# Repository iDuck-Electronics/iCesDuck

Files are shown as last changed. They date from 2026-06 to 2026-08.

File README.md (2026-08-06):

# iCesDuck

<p align="center">
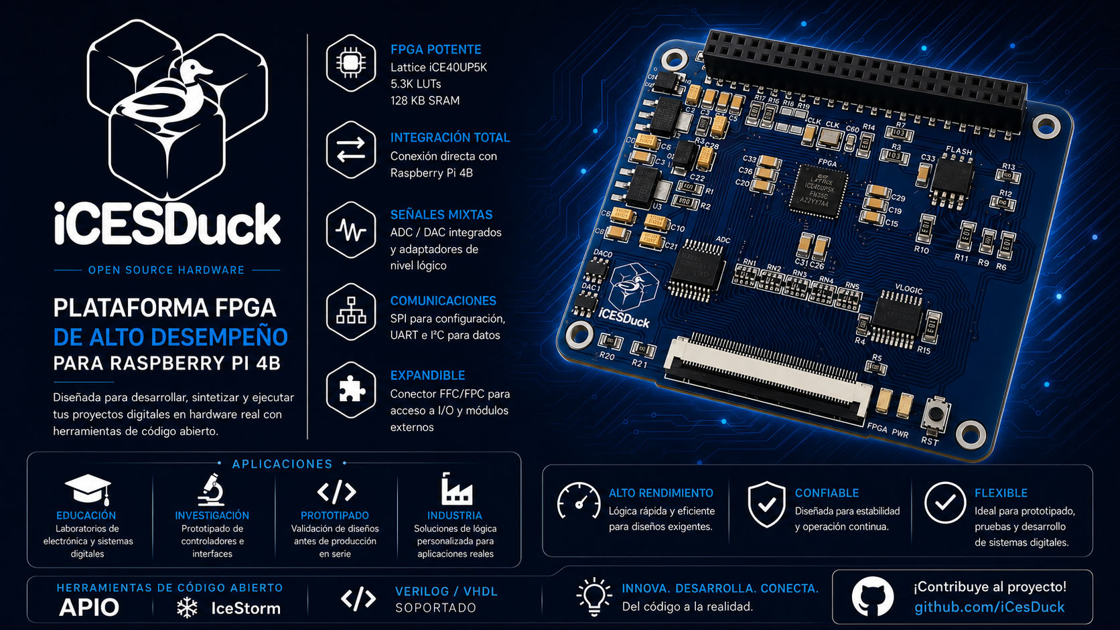
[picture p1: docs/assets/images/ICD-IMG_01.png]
iCesDuck — Plataforma FPGA para Raspberry Pi 4B
  
</p>

<p align="center">
  
  
  
  
</p>

<p align="center">
  <strong>Plataforma FPGA de código abierto para Raspberry Pi 4B</strong><br>
  Síntesis, programación y supervisión de lógica digital en una arquitectura compacta, modular y orientada a la experimentación.
</p>

---

## Descripción general

**iCesDuck** es una placa de desarrollo basada en la FPGA **Lattice iCE40UP5K**, diseñada para trasladar proyectos escritos en **Verilog** y **VHDL** desde la simulación HDL hasta su ejecución en hardware real.

La **Raspberry Pi 4B** funciona como sistema anfitrión y entorno principal de trabajo: realiza la síntesis, genera el bitstream, programa la FPGA y supervisa el comportamiento de la plataforma. Esta integración permite desarrollar, probar y depurar diseños digitales sin depender de herramientas propietarias o programadores externos especializados.

La placa incorpora recursos para trabajar con señales digitales y mixtas, entre ellos:

- FPGA programable **Lattice iCE40UP5K**.
- Convertidores **ADC** y **DAC**.
- Adaptadores de nivel lógico.
- Memoria de configuración.
- Reloj de **48 MHz**.
- Comunicación mediante **SPI**, **I²C** y **UART**.
- Conector **FFC/FPC** para expansión y acceso a señales externas.
- Conector GPIO espejo compatible con Raspberry Pi 4B.

<p align="center">
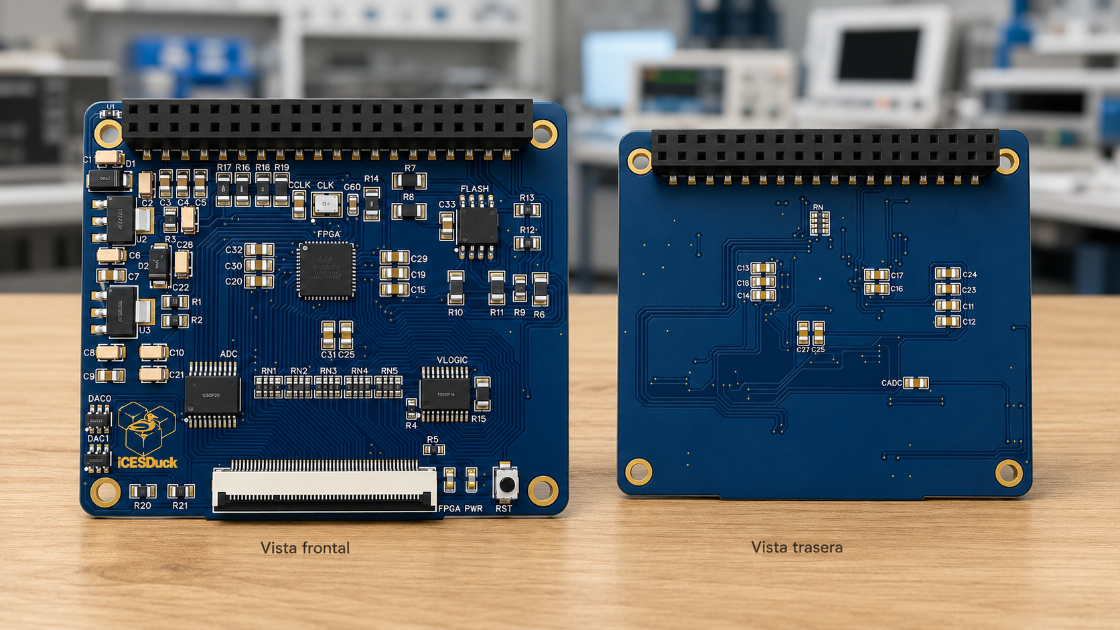
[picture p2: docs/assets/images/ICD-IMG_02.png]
Vista frontal y posterior de la placa iCesDuck
  
</p>

> **Objetivo del proyecto:** ofrecer una plataforma abierta y documentada para aprender, investigar y prototipar sistemas digitales con FPGA, utilizando la Raspberry Pi como unidad de desarrollo, programación y supervisión.

<p align="center">
  <a href="docs/README.md">
    
  </a>
  &nbsp;
  <a href="hardware/README.md">
    
  </a>
  &nbsp;
  <a href="software/README.md">
    
  </a>
</p>

<p align="center">
  <a href="examples/README.md">
    
  </a>
  &nbsp;
  <a href="tests/README.md">
    
  </a>
</p>

---

## Características principales

<table>
  <thead>
    <tr>
      <th width="20%" align="left">Característica</th>
      <th width="24%" align="left">Especificación</th>
      <th width="48%" align="center">Distribución de componentes</th>
    </tr>
  </thead>
  <tbody>
    <tr>
      <td><strong>FPGA</strong></td>
      <td>Lattice iCE40UP5K</td>
      <td rowspan="11" align="center" valign="middle">
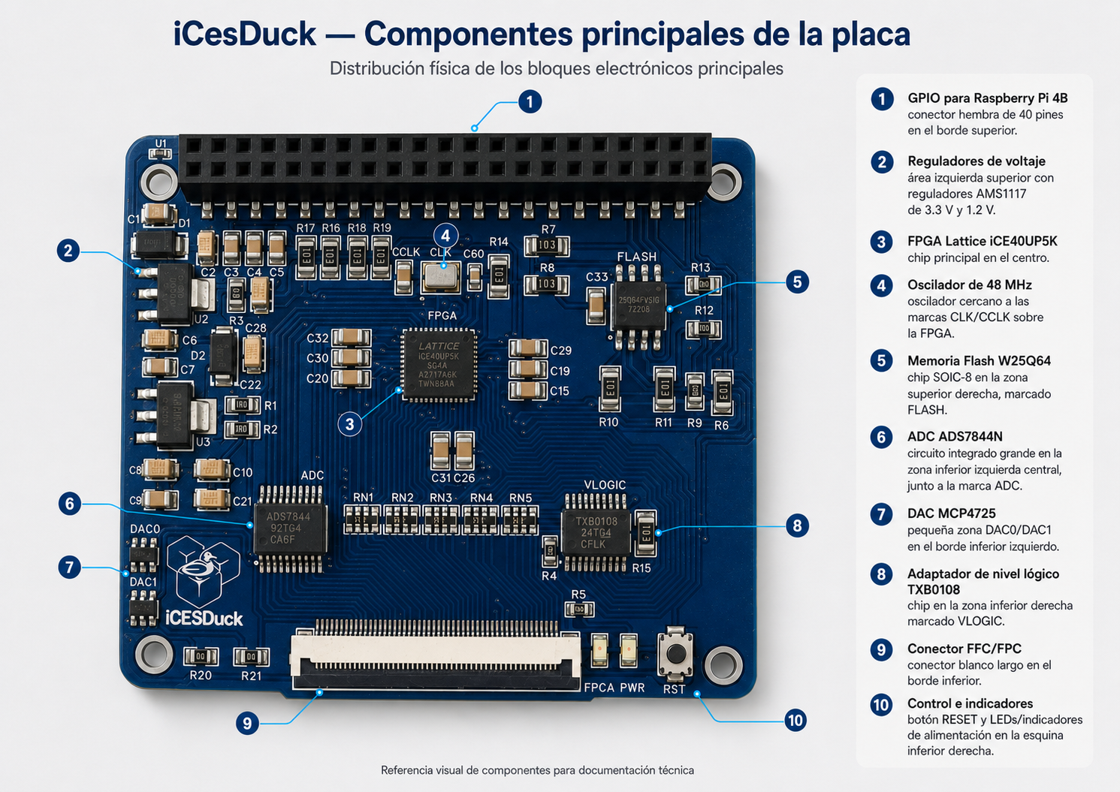
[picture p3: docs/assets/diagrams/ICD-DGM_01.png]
Distribución de los principales componentes de iCesDuck
        
        <br>
        <sub><em>Distribución general de los principales bloques electrónicos de la placa.</em></sub>
      </td>
    </tr>
    <tr><td><strong>Capacidad lógica</strong></td><td>5,280 LUTs</td></tr>
    <tr><td><strong>Memoria interna</strong></td><td>128 KB de SRAM</td></tr>
    <tr><td><strong>Compatibilidad</strong></td><td>Raspberry Pi 4B</td></tr>
    <tr><td><strong>Nivel lógico principal</strong></td><td>3.3 V</td></tr>
    <tr><td><strong>Interfaces</strong></td><td>SPI, I²C y UART</td></tr>
    <tr><td><strong>Conversión de señales</strong></td><td>ADC y DAC integrados</td></tr>
    <tr><td><strong>Reloj</strong></td><td>48 MHz</td></tr>
    <tr><td><strong>Lenguajes HDL</strong></td><td>Verilog y VHDL</td></tr>
    <tr><td><strong>Toolchain</strong></td><td>APIO, Yosys, nextpnr e IceStorm</td></tr>
    <tr><td><strong>Expansión</strong></td><td>GPIO espejo y conector FFC/FPC</td></tr>
  </tbody>
</table>

---

## Aplicaciones

- **Educación:** laboratorios de sistemas digitales, FPGA, arquitectura de computadores y electrónica embebida.
- **Investigación:** validación de controladores, interfaces digitales y lógica de propósito específico.
- **Prototipado:** pruebas funcionales antes de migrar un diseño a otra FPGA o a una solución dedicada.
- **Depuración HDL:** ejecución de testbench, comparación de resultados y validación en hardware real.
- **Señales mixtas:** adquisición, procesamiento y generación de señales mediante ADC, DAC y adaptadores de nivel.

---

## Revisiones de hardware

El desarrollo de iCesDuck se mantiene en evolución continua. Conforme se identifiquen errores, se validen nuevos bloques, se incorporen mejoras o se generen nuevas revisiones de hardware, los cambios correspondientes serán documentados y publicados en este repositorio para mantener la trazabilidad técnica del proyecto.

| Revisión | Estado | Ubicación |
|---|---|---|
| **V1.A1** | Primera revisión funcional con errores identificados | [`iCesDuck V1.A1`](hardware/boards-iCesDuck/v1-a1/) |
| **V1.A2** | Segunda revisión en desarrollo | [`iCesDuck V1.A1`](hardware/boards-iCesDuck/v1-a2/) |

---

## Explora iCesDuck

El repositorio está organizado por áreas especializadas. Cada una representa una etapa concreta del desarrollo, desde el diseño electrónico de la placa hasta la creación, programación y validación de proyectos HDL.

> **Ruta recomendada:** comienza con la documentación, ejecuta un ejemplo HDL y después entra al software, al hardware o a las pruebas según el área que quieras desarrollar.

<details>
<summary>
  <strong>🔷 Hardware iCesDuck</strong>
  <code>PCB</code>
  <code>EasyEDA</code>
  <code>fabricación</code>
</summary>

<br>

<div align="center">
  Diseño electrónico, revisiones y fabricación de iCesDuck
  <br>
  <sub><em>Diseño electrónico, revisiones físicas y recursos para reproducir la plataforma.</em></sub>
</div>

<br>

<p align="center">
  
  
  
</p>

Documenta la evolución física de la plataforma: esquemáticos, PCB, revisiones, modelos 3D, archivos de fabricación y evidencias de validación.

**Úsala para:** estudiar la placa, comparar versiones, recuperar las fuentes originales o preparar el hardware para fabricación.

<p align="right">
  <a href="hardware/README.md">
    
  </a>
</p>

</details>

<details>
<summary>
  <strong>⚙️ iDuck-Upload</strong>
  <code>Raspberry Pi</code>
  <code>SPI</code>
  <code>programación</code>
</summary>

<br>

<div align="center">
  Programación y control de iCesDuck desde Raspberry Pi
  <br>
  <sub><em>Preparación, conversión y carga de la configuración mediante Raspberry Pi.</em></sub>
</div>

<br>

<p align="center">
  
  
  
</p>

Reúne las herramientas utilizadas para preparar, convertir y transmitir la configuración hacia la FPGA y su memoria mediante SPI sobre GPIO.

**Úsala para:** instalar el cargador, configurar pines, convertir archivos y programar iCesDuck desde Raspberry Pi.

<p align="right">
  <a href="software/README.md">
    
  </a>
</p>

</details>

<details>
<summary>
  <strong>🧩 Diseños HDL</strong>
  <code>Verilog</code>
  <code>VHDL</code>
  <code>bitstreams</code>
</summary>

<br>

<div align="center">
  Desarrollo de diseños HDL para iCesDuck
  <br>
  <sub><em>Diseño, simulación, síntesis y generación de configuraciones para la FPGA.</em></sub>
</div>

<br>

<p align="center">
  
  
  
</p>

Concentra el código de hardware, las restricciones de pines, los bancos de prueba y los bitstreams producidos para la FPGA Lattice iCE40UP5K.

**Úsala para:** desarrollar lógica digital, simular diseños, definir pines o preparar un proyecto para síntesis.

<p align="right">
  <a href="hdl/README.md">
    
  </a>
</p>

</details>

<details>
<summary>
  <strong>💡 Ejemplos</strong>
  <code>aprendizaje</code>
  <code>demostraciones</code>
  <code>prácticas</code>
</summary>

<br>

<div align="center">
  Ejemplos y proyectos demostrativos de iCesDuck
  <br>
  <sub><em>Proyectos progresivos para conocer y validar las funciones de iCesDuck.</em></sub>
</div>

<br>

<p align="center">
  
  
  
</p>

Presenta proyectos progresivos para conocer la plataforma, comprobar sus interfaces y reutilizar diseños funcionales como base para nuevos desarrollos.

**Úsala para:** ejecutar una primera prueba, aprender el flujo de trabajo o validar bloques específicos de la placa.

<p align="right">
  <a href="examples/README.md">
    
  </a>
</p>

</details>

<details>
<summary>
  <strong>🧪 Pruebas y validación</strong>
  <code>hardware</code>
  <code>software</code>
  <code>HDL</code>
</summary>

<br>

<div align="center">
  Pruebas y validación de iCesDuck
  <br>
  <sub><em>Procedimientos y evidencias para comprobar el funcionamiento del sistema.</em></sub>
</div>

<br>

<p align="center">
  
  
  
</p>

Documenta procedimientos, mediciones, incidencias, resultados y evidencias para comprobar el funcionamiento independiente e integrado del sistema.

**Úsala para:** reproducir pruebas, revisar resultados, registrar fallos o validar nuevas revisiones.

<p align="right">
  <a href="tests/README.md">
    
  </a>
</p>

</details>

<details>
<summary>
  <strong>📘 Documentación</strong>
  <code>inicio</code>
  <code>arquitectura</code>
  <code>protocolos</code>
</summary>

<br>

<div align="center">
  Documentación técnica de iCesDuck
  <br>
  <sub><em>Guías, arquitectura y referencias técnicas para comprender y ampliar la plataforma.</em></sub>
</div>

<br>

<p align="center">
  
  
  
</p>

Explica cómo instalar, comprender, utilizar, mantener y ampliar iCesDuck mediante guías, referencias técnicas y documentación de arquitectura.

**Úsala para:** preparar el entorno, consultar interfaces, entender el sistema o documentar nuevas funciones.

<p align="right">
  <a href="docs/README.md">
    
  </a>
</p>

</details>

---

## Estado del proyecto

| Fecha | Versión | Estado | Notas |
|---|---|---|---|
| **05-03-2025** | **V1.A1** | Funcional | Placa ensamblada, FPGA programada correctamente, reguladores de 3.3 V y 1.2 V estables y reloj de 48 MHz validado. ADC y DAC pendientes de validación completa. |
| **17-09-2025** | **V1.A1** | Fallo identificado | Se detectó un cruce incorrecto en líneas de comunicación relacionadas con la memoria de configuración y los GPIO de la Raspberry Pi 4B. La FPGA puede programarse directamente, pero no conserva la configuración después de un reinicio. |
| **Planificada: 03-08-2026** | **V2.A1** | En desarrollo | Corrección de líneas de comunicación, revisión de SPI, I²C y UART, ampliación de documentación y preparación de nuevos ejemplos funcionales. |

---

## Arquitectura del sistema

iCesDuck utiliza una arquitectura **host–dispositivo**, en la que la **Raspberry Pi 4B** funciona como unidad de desarrollo, programación y supervisión, mientras que la placa **iCesDuck** actúa como plataforma de ejecución para la lógica digital.

El flujo comienza en la Raspberry Pi, donde el usuario desarrolla el diseño en **Verilog o VHDL**. Mediante **APIO**, **Yosys**, **nextpnr** e **IceStorm**, el código HDL se sintetiza y se convierte en un archivo binario de configuración. Posteriormente, una herramienta de carga transforma el archivo generado al formato requerido y lo transmite por **SPI**, utilizando los GPIO de la Raspberry Pi, hacia la FPGA y la memoria de configuración de iCesDuck.

Una vez programada, la plataforma ejecuta el diseño directamente en hardware y permite utilizar sus recursos integrados:

- FPGA **Lattice iCE40UP5K**.
- Memoria de configuración.
- Convertidores **ADC** y **DAC**.
- Adaptador de nivel lógico **VLOGIC**.
- Reloj de **48 MHz**.
- Conector de expansión **FFC/FPC**.
- GPIO de comunicación y control.

<p align="center">
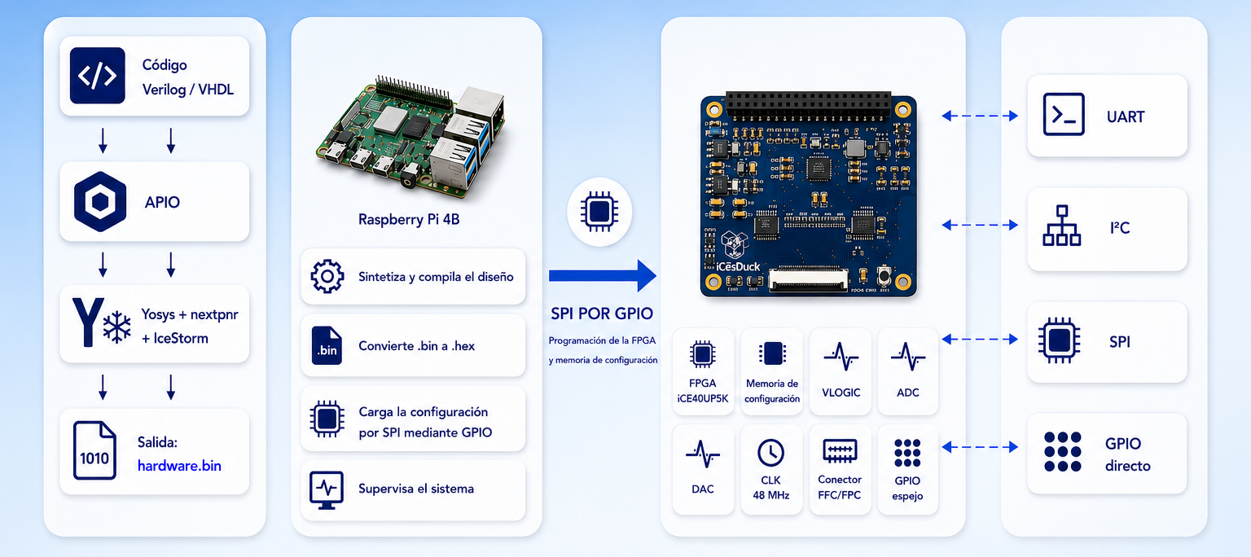
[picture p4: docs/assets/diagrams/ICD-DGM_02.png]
Flujo de síntesis, programación, ejecución y comunicación de iCesDuck
  
</p>

<p align="center">
  <em>Flujo general desde el diseño HDL en la Raspberry Pi 4B hasta la ejecución y comunicación con la plataforma iCesDuck.</em>
</p>

### Función de cada elemento

- **Raspberry Pi 4B:** proporciona el entorno de desarrollo, sintetiza el diseño HDL, genera los archivos de configuración, controla la programación mediante GPIO y supervisa el funcionamiento del sistema.
- **Interfaz SPI:** constituye el enlace principal para transferir la configuración hacia la FPGA y la memoria no volátil.
- **Plataforma iCesDuck:** almacena y ejecuta la lógica programada, además de proporcionar acceso a los periféricos, señales y conectores de expansión.
- **Interfaces de operación:** una vez cargado el diseño, la comunicación entre la Raspberry Pi, la FPGA y otros dispositivos puede realizarse mediante **UART**, **I²C**, **SPI** y GPIO directo.

Esta organización separa el proceso de desarrollo del proceso de ejecución: la Raspberry Pi administra la síntesis y la programación, mientras que iCesDuck implementa el diseño digital en hardware y mantiene disponibles sus recursos de adquisición, generación y adaptación de señales.

### Componentes principales

<p>La arquitectura distribuye sus funciones entre el sistema anfitrión y el dispositivo programable:</p>

<table>
<tr>
<td width="50%" valign="top">

<p align="center">
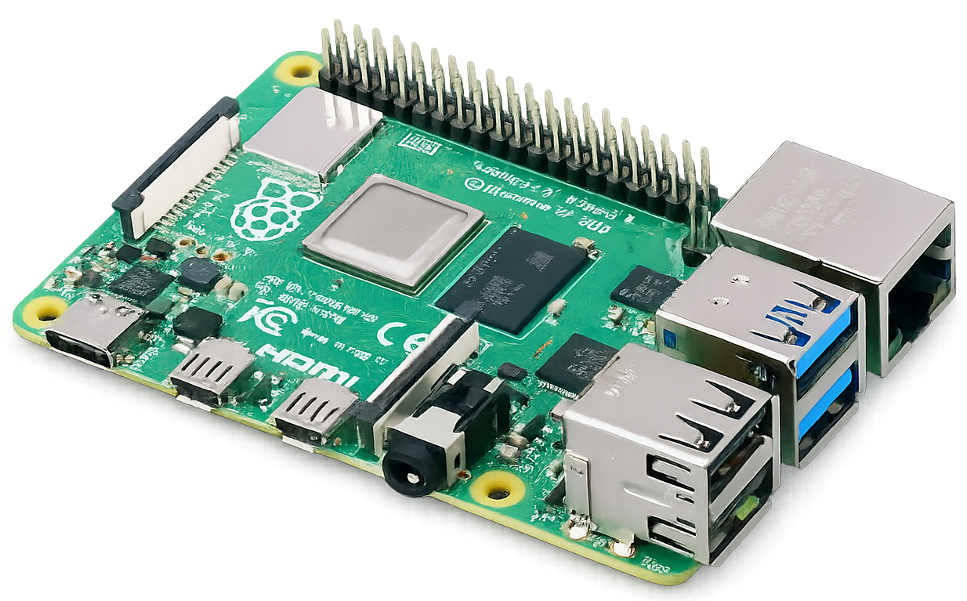
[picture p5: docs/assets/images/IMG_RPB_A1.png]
Raspberry Pi 4B
  
</p>

<h4 align="center">Raspberry Pi 4B</h4>
<p align="center"><strong>Host de desarrollo, programación y supervisión</strong></p>
<hr>

<ul>
<li>Proporciona el entorno de desarrollo y compilación.</li>
<li>Procesa diseños escritos en <strong>Verilog</strong> y <strong>VHDL</strong>.</li>
<li>Ejecuta la síntesis mediante APIO, Yosys, nextpnr e IceStorm.</li>
<li>Genera el archivo <code>hardware.bin</code>.</li>
<li>Convierte la configuración al formato requerido para la carga.</li>
<li>Programa la FPGA y la memoria mediante SPI sobre GPIO.</li>
<li>Supervisa señales de estado como <code>CDONE</code>.</li>
<li>Permite controlar y depurar el sistema en tiempo real.</li>
</ul>

<p align="center">
<kbd>Desarrollo</kbd>
<kbd>Síntesis</kbd>
<kbd>Programación</kbd>
<kbd>Supervisión</kbd>
</p>

</td>
<td width="50%" valign="top">

<p align="center">
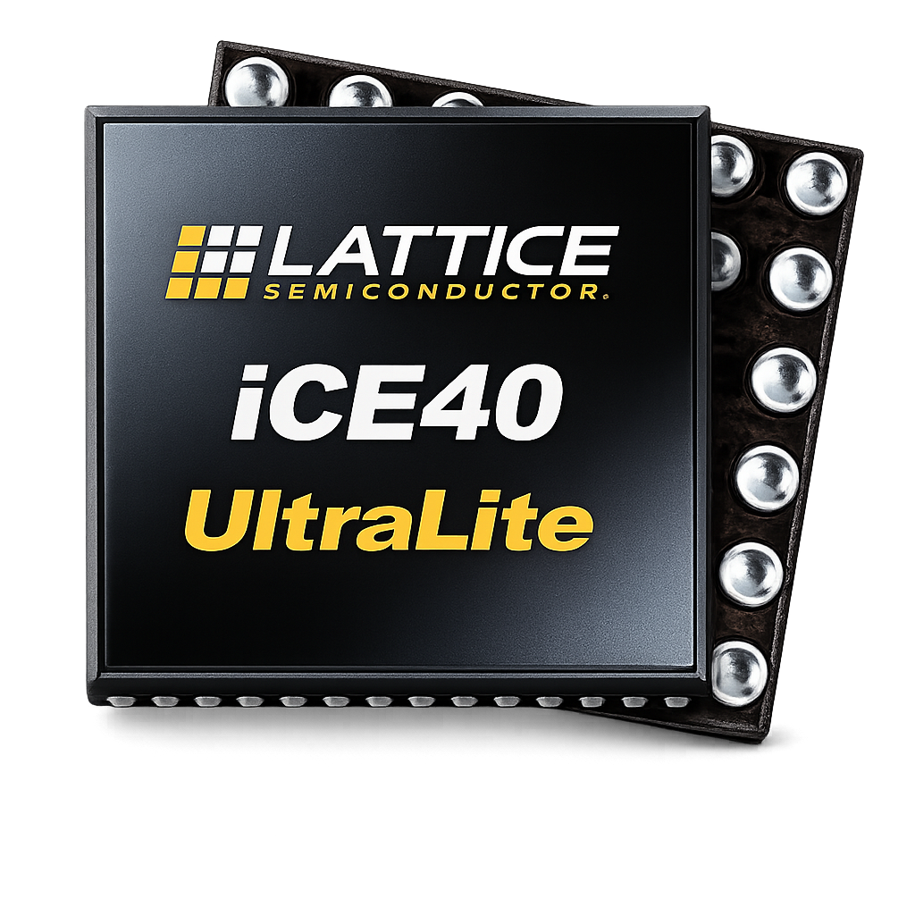
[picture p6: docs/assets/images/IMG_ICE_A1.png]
FPGA Lattice iCE40UP5K
  
</p>

<h4 align="center">FPGA Lattice iCE40UP5K</h4>
<p align="center"><strong>Unidad de ejecución de lógica digital</strong></p>
<hr>

<ul>
<li>Implementa el diseño sintetizado directamente en hardware.</li>
<li>Integra <strong>5,280 LUTs</strong> para lógica combinacional y secuencial.</li>
<li>Dispone de <strong>128 KB de SRAM</strong> interna.</li>
<li>Incluye multiplicadores embebidos para procesamiento digital.</li>
<li>Incorpora PLL para generación y ajuste de frecuencias.</li>
<li>Controla los periféricos y señales internas de la plataforma.</li>
<li>Interactúa con ADC, DAC, VLOGIC, reloj y expansión FFC/FPC.</li>
<li>Es compatible con herramientas de síntesis de código abierto.</li>
</ul>

<p align="center">
<kbd>Ejecución</kbd>
<kbd>Lógica digital</kbd>
<kbd>Periféricos</kbd>
<kbd>Expansión</kbd>
</p>

</td>
</tr>
</table>

> La Raspberry Pi prepara, programa y supervisa el sistema; la FPGA convierte el diseño sintetizado en lógica digital ejecutándose directamente sobre hardware.

---

## Flujo de trabajo

El proceso de desarrollo de iCesDuck se organiza en seis etapas: diseño HDL, síntesis, generación del bitstream, carga, ejecución y supervisión.

<p align="center">
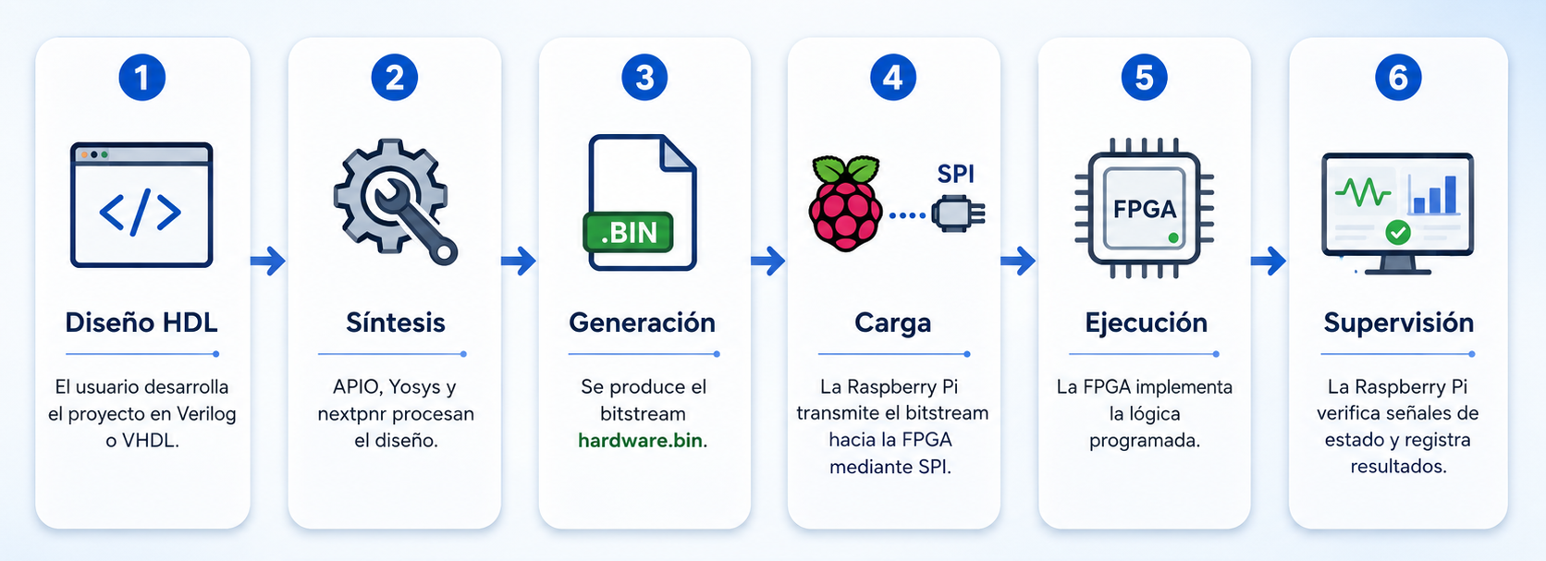
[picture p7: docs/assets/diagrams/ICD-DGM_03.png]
Flujo de trabajo de síntesis, programación, ejecución y supervisión de iCesDuck
  
</p>

<p align="center">
  <em>Flujo general desde el desarrollo del código HDL hasta la ejecución y validación del diseño sobre hardware real.</em>
</p>

### Etapas del proceso

1. **Diseño HDL:** el usuario desarrolla el proyecto en Verilog o VHDL.
2. **Síntesis:** APIO, Yosys y nextpnr procesan el diseño.
3. **Generación:** se produce el bitstream `hardware.bin`.
4. **Carga:** la Raspberry Pi transmite el bitstream hacia la FPGA mediante SPI.
5. **Ejecución:** la FPGA implementa la lógica programada.
6. **Supervisión:** la Raspberry Pi verifica señales de estado y registra resultados.

> Este flujo facilita ciclos rápidos de diseño, prueba, corrección y validación sobre hardware real.

---

## Visión del proyecto

iCesDuck nace con el propósito de acercar el desarrollo con FPGA a estudiantes, investigadores y profesionales mediante una plataforma abierta, accesible y reproducible.

El proyecto busca reducir la separación entre la simulación HDL y la implementación física, integrando en una sola plataforma la síntesis, la programación, la supervisión y el acceso a señales digitales y mixtas.

<p align="center">
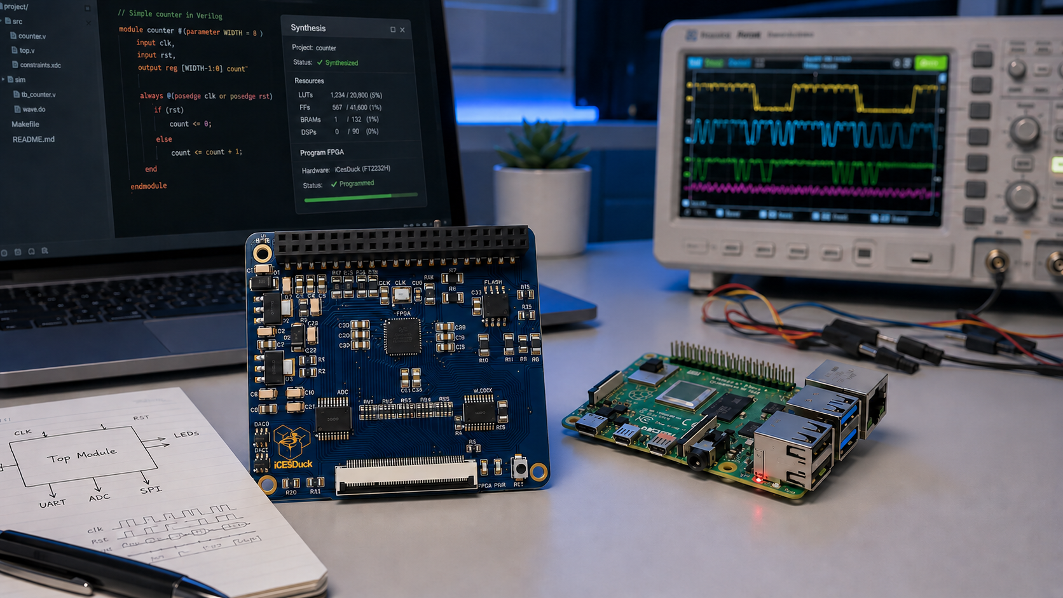
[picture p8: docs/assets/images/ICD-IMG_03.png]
Entorno de desarrollo, programación y validación de iCesDuck con Raspberry Pi 4B y equipo de laboratorio
  
</p>

<p align="center">
  <em>iCesDuck integra el desarrollo HDL, la programación de la FPGA y la validación de señales sobre hardware real.</em>
</p>

Actualmente, iCesDuck se encuentra en una etapa de **maduración técnica**. Las revisiones de hardware, el software de carga, los ejemplos y la documentación continúan evolucionando conforme se validan nuevos bloques y se corrigen los problemas identificados en versiones anteriores.

---

## Contribuciones

Las contribuciones pueden incluir:

- Reportes de errores.
- Validación de nuevas revisiones de hardware.
- Mejoras en el cargador de la FPGA.
- Ejemplos Verilog o VHDL.
- Testbench y pruebas automatizadas.
- Correcciones y ampliaciones de documentación.

Antes de realizar cambios importantes, revisa la estructura del repositorio y procura mantener separadas las áreas de hardware, software, HDL, pruebas y documentación.

---

## Agradecimientos

- **FPGAwars**, por APIO y su ecosistema de herramientas.
- **Clifford Wolf**, por IceStorm y Yosys.
- **YosysHQ**, por nextpnr y herramientas relacionadas.
- Comunidad de hardware y software de código abierto.

---

## Recursos externos

- [Lattice Semiconductor](https://www.latticesemi.com/)
- [APIO](https://github.com/FPGAwars/apio)
- [Project IceStorm](https://github.com/YosysHQ/icestorm)
- [Yosys](https://github.com/YosysHQ/yosys)
- [nextpnr](https://github.com/YosysHQ/nextpnr)
- [Documentación de GPIO de Raspberry Pi](https://www.raspberrypi.com/documentation/computers/raspberry-pi.html)

---

## Licencia

Este proyecto se distribuye bajo una licencia abierta. Consulta el archivo [`LICENSE`](LICENSE) para conocer sus términos y condiciones.

---
<p align="center">
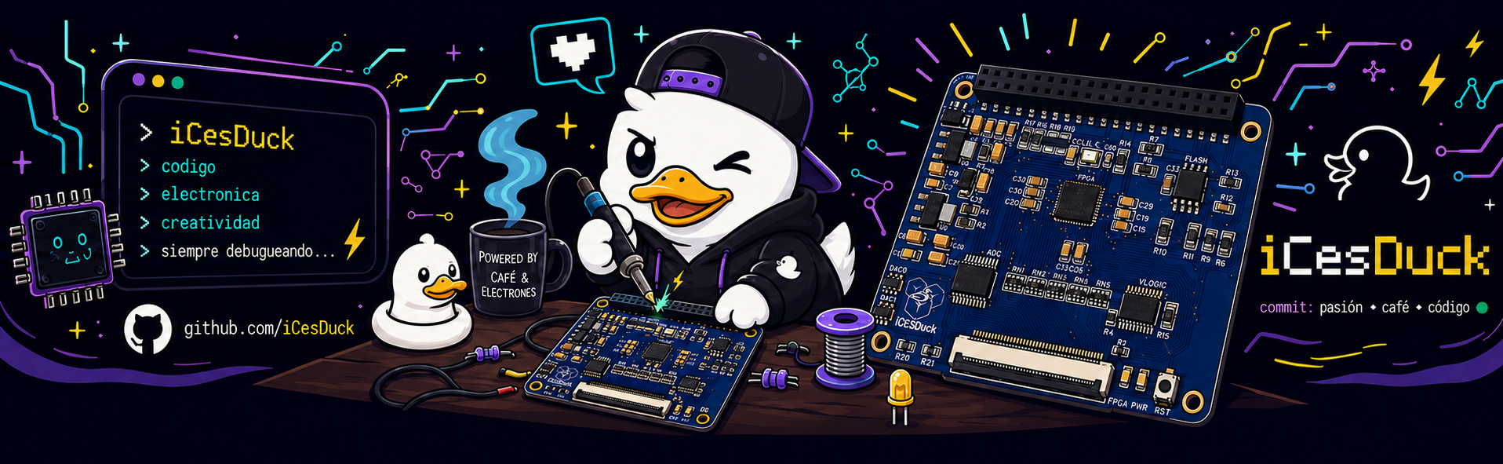
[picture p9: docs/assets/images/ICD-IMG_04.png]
  
</p>

<p align="center">
  <strong>iCesDuck</strong><br>
  FPGA · Raspberry Pi · Verilog · VHDL · Open Source
</p>

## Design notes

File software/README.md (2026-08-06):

<div align="center">

# Software · iCesDuck

### Herramientas de carga, control y soporte para la plataforma iCesDuck

**Raspberry Pi · GPIO · FPGA iCE40UP5K · Linux ARM64**

</div>

---

<!--
IMAGEN PENDIENTE
Ruta sugerida: utilities/assets/software-banner.png
Descripción: Banner general del área de software de iCesDuck.
-->

<p align="center">
  Banner del área de software de iCesDuck
</p>

> [!NOTE]
> Este directorio concentra las herramientas de software que permiten preparar, cargar, documentar y mantener los componentes programables de iCesDuck.

## Navegación rápida

- [Descripción general](#descripción-general)
- [Estructura del directorio](#estructura-del-directorio)
- [iDuck Upload](#iduck-upload)
- [Versiones disponibles](#versiones-disponibles)
- [Utilities](#utilities)
- [Flujo de trabajo](#flujo-de-trabajo)
- [Uso general](#uso-general)
- [Documentación e imágenes](#documentación-e-imágenes)
- [Buenas prácticas](#buenas-prácticas)

---

## Descripción general

El apartado `software/` reúne los programas y recursos utilizados por la Raspberry Pi para interactuar con el hardware de iCesDuck.

Su función principal es mantener separadas y organizadas:

- las herramientas ejecutables;
- las diferentes revisiones del cargador;
- la documentación de arquitectura;
- los diagramas e imágenes del proyecto;
- los recursos auxiliares necesarios para instalación, validación y mantenimiento.

Esta organización evita concentrar todo el proyecto en un único archivo y permite que cada versión conserve su propio código, ejecutable, documentación y archivos compatibles.

---

## Estructura del directorio

```text
software/
├── uploader/
│   ├── iDuck_Upload-v1.A0/
│   └── iDuck_Upload-v1.A1/
├── utilities/
│   ├── architecture/
│   └── assets/
└── README.md
```

| Ruta | Propósito |
|---|---|
| `uploader/` | Almacena las versiones del software encargado de cargar la configuración en la FPGA. |
| `uploader/iDuck_Upload-v1.A0/` | Conserva una revisión independiente del cargador iDuck Upload. |
| `uploader/iDuck_Upload-v1.A1/` | Conserva otra revisión del cargador sin reemplazar la versión anterior. |
| `utilities/architecture/` | Contiene diagramas, flujos, mapas de conexión y documentación de arquitectura. |
| `utilities/assets/` | Contiene banners, capturas, fotografías, iconos y demás recursos visuales. |
| `README.md` | Presenta una vista general del área de software y orienta al usuario dentro del directorio. |

> [!IMPORTANT]
> Cada versión del cargador debe conservar su propio `README.md`, bitstream, código fuente, ejecutable y notas de cambios. No se recomienda mezclar archivos entre versiones sin comprobar su compatibilidad.

---

## iDuck Upload

**iDuck Upload** es la utilidad encargada de transferir el archivo de configuración de la FPGA desde una Raspberry Pi hacia la tarjeta iCesDuck.

La implementación revisada está desarrollada en C y utiliza la biblioteca `bcm2835` para controlar directamente los GPIO de la Raspberry Pi. La transmisión se realiza mediante una interfaz serial implementada por software, conocida como **bit-banging**.

### Funcionamiento general

```mermaid
flowchart LR
    A[hardware.bin] --> B[iDuck Upload]
    B --> C[GPIO de Raspberry Pi]
    C --> D[Señales de configuración]
    D --> E[FPGA iCE40UP5K]
    E --> F[Validación mediante CDONE]
```

Durante una carga normal, el programa realiza las siguientes acciones:

1. Inicializa el acceso a los GPIO.
2. Coloca la FPGA en modo de configuración.
3. Controla las señales de reinicio, selección, reloj y datos.
4. Transmite el bitstream byte por byte y bit por bit.
5. Supervisa la señal `CDONE` para determinar si la configuración terminó correctamente.

<details>
<summary><strong>Señales principales utilizadas</strong></summary>

| Señal | Función general |
|---|---|
| `SDO` | Envía los datos desde la Raspberry Pi hacia la FPGA. |
| `SCLK` | Genera el reloj de configuración. |
| `CSN` | Selecciona la FPGA durante la transferencia. |
| `CRESET_B` | Reinicia la lógica de configuración de la FPGA. |
| `CDONE` | Confirma si la configuración fue aceptada. |
| `SDI` | Entrada reservada para comunicación o funciones futuras. |

</details>

### Alcance del cargador

El cargador permite que la Raspberry Pi funcione como controlador de configuración de iCesDuck, reduciendo la dependencia de un programador externo durante el arranque o durante pruebas de desarrollo.

La versión actual debe manejarse como una implementación en evolución. Antes de liberar una revisión estable deben validarse la secuencia de configuración, los tiempos, los relojes finales y el comportamiento de `CDONE`.

---

<!--
IMAGEN PENDIENTE
Ruta sugerida: utilities/assets/uploader-flow.png
Descripción: Raspberry Pi conectada a iCesDuck mostrando SDO, SCLK, CSN, CRESET_B y CDONE.
-->

<p align="center">
  Flujo de carga desde Raspberry Pi hacia iCesDuck
</p>

---

## Versiones disponibles

Las diferentes versiones del cargador se encuentran dentro de:

```text
software/uploader/
```

Actualmente, la estructura contempla:

```text
iDuck_Upload-v1.A0/
iDuck_Upload-v1.A1/
```

Cada carpeta representa una revisión independiente. Esto permite:

- conservar versiones anteriores funcionales;
- comparar cambios entre revisiones;
- evitar que una actualización sobrescriba una entrega estable;
- mantener bitstreams compatibles con una revisión específica;
- documentar errores, mejoras y pruebas de manera separada.

### Convención sugerida de versionado

```text
v1.A0
│ │ └── número de revisión
│ └──── etapa o serie de desarrollo
└────── versión principal
```

> [!TIP]
> Antes de ejecutar una versión, revise siempre el `README.md` ubicado dentro de su carpeta. Ese archivo debe indicar requisitos, dependencias, compatibilidad, método de instalación y estado de validación.

### Cómo localizar una versión

```bash
cd software/uploader
ls
```

Después, ingrese a la revisión que desea utilizar:

```bash
cd iDuck_Upload-v1.A0
```

Para cambiar de revisión, regrese a `uploader/` y seleccione otra carpeta. No copie únicamente el ejecutable: mantenga juntos los archivos pertenecientes a la misma versión.

---

## Utilities

El directorio `utilities/` reúne los recursos compartidos por las diferentes versiones del software.

### `utilities/architecture/`

Este apartado debe utilizarse para almacenar:

- diagramas de bloques;
- diagramas de secuencia;
- arquitectura de software;
- mapas de conexión GPIO;
- flujos de instalación;
- procesos de compilación;
- relación entre Raspberry Pi, iCesDuck y FPGA;
- documentación técnica complementaria.

Ejemplo de organización:

```text
utilities/architecture/
├── software-overview.md
├── uploader-sequence.md
├── gpio-map.md
└── diagrams/
```

### `utilities/assets/`

Este apartado concentra los recursos visuales usados por los archivos Markdown:

```text
utilities/assets/
├── software-banner.png
├── software-architecture.png
├── uploader-flow.png
├── version-comparison.png
└── screenshots/
```

Se recomienda utilizar nombres descriptivos, evitar espacios y conservar las imágenes en formatos como PNG, JPG, SVG o WebP.

---

<!--
IMAGEN PENDIENTE
Ruta sugerida: utilities/assets/software-architecture.png
Descripción: Diagrama general de los componentes distribuidos dentro de software/.
-->

<p align="center">
  Arquitectura general del apartado software
</p>

---

## Flujo de trabajo

```mermaid
flowchart TD
    A[Seleccionar versión] --> B[Leer README de la versión]
    B --> C[Comprobar dependencias]
    C --> D[Validar hardware.bin]
    D --> E[Compilar o preparar ejecutable]
    E --> F[Conectar Raspberry Pi e iCesDuck]
    F --> G[Ejecutar iDuck Upload]
    G --> H{CDONE en alto}
    H -- Sí --> I[Configuración completada]
    H -- No --> J[Revisar conexiones, bitstream y secuencia]
```

### Ruta recomendada para un nuevo usuario

1. Leer este `README.md`.
2. Revisar `utilities/architecture/` para comprender la integración general.
3. Entrar a `uploader/`.
4. Seleccionar la versión requerida.
5. Leer la documentación propia de esa versión.
6. Confirmar que el ejecutable y `hardware.bin` pertenecen a la misma revisión.
7. Ejecutar las pruebas indicadas antes de utilizarlo sobre hardware definitivo.

---

## Uso general

El procedimiento exacto puede cambiar entre versiones. De forma general, una revisión puede utilizarse de la siguiente manera:

```bash
cd software/uploader/<version>
chmod +x iDuck-RP-Upload
sudo ./iDuck-RP-Upload
```

En sistemas sin `sudo`, como algunas imágenes basadas en Buildroot, puede ser necesario ejecutar con una cuenta que tenga acceso directo a GPIO.

### Archivos que puede incluir una versión

```text
iDuck_Upload-vX.XX/
├── README.md
├── iDuck-RP-Upload.c
├── iDuck-RP-Upload
├── hardware.bin
├── install.sh
└── CHANGELOG.md
```

> [!CAUTION]
> El nombre y contenido exacto de los archivos puede variar entre versiones. Utilice siempre las instrucciones del `README.md` interno.

---

## Documentación e imágenes

Para mantener una presentación clara y profesional, las imágenes generales deben almacenarse en `utilities/assets/` y referenciarse mediante rutas relativas.

Ejemplo:

```md
![Arquitectura de software](utilities/assets/software-architecture.png)
```

### Imágenes recomendadas para completar este README

| Imagen | Ruta sugerida | Contenido |
|---|---|---|
| Banner principal | `utilities/assets/software-banner.png` | Identidad visual del apartado de software. |
| Arquitectura general | `utilities/assets/software-architecture.png` | Relación entre carpetas, herramientas y hardware. |
| Flujo del cargador | `utilities/assets/uploader-flow.png` | Raspberry Pi, GPIO, iCesDuck y FPGA. |
| Comparación de versiones | `utilities/assets/version-comparison.png` | Diferencias principales entre revisiones. |
| Captura de terminal | `utilities/assets/screenshots/upload-success.png` | Ejemplo de una carga completada correctamente. |

---

## Buenas prácticas

- Mantener una carpeta independiente por versión.
- Agregar un `README.md` dentro de cada revisión.
- Registrar cambios en un `CHANGELOG.md`.
- No reemplazar una versión estable durante el desarrollo.
- Mantener juntos código fuente, ejecutable y bitstream compatibles.
- Verificar permisos de acceso a GPIO antes de ejecutar.
- Documentar la arquitectura objetivo y el sistema operativo compatible.
- Validar señales con analizador lógico antes de una liberación estable.
- No conectar señales de 5 V directamente a los GPIO de la Raspberry Pi.
- Mantener una tierra común entre la Raspberry Pi y la tarjeta iCesDuck.

---

## Estado del área

| Componente | Estado |
|---|---|
| Organización por versiones | Implementada en la estructura del repositorio. |
| Cargador mediante GPIO | Disponible como prototipo funcional. |
| Documentación general | En desarrollo. |
| Documentación individual por versión | Debe mantenerse dentro de cada carpeta. |
| Recursos de arquitectura | Organizados en `utilities/architecture/`. |
| Recursos visuales | Organizados en `utilities/assets/`. |
| Validación completa de la secuencia FPGA | Pendiente de pruebas y documentación final. |

---

## Licencia

La licencia del contenido de `software/` debe mantenerse alineada con la licencia principal del repositorio iCesDuck. Las bibliotecas y herramientas de terceros conservan sus propios términos de licencia.

---

<div align="center">

### iCesDuck

**Hardware · Firmware · Software · Networking**

</div>

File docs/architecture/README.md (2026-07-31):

#### Flujo de programación

El proceso de carga del diseño en la FPGA consta de tres etapas:

  #### Inclusión de dependencias

  El programa requiere dos inclusiones fundamentales:

  ```C
  #include ".tempHex.c"      // Vector hexadecimal del bitstream
  #include <bcm2835.h>       // Control de GPIO
  ```

  **`.tempHex.c`**: Archivo generado por `convertir_binario_a_c()` que contiene el vector `bitmap[]` con los datos del bitstream en formato hexadecimal. **`bcm2835.h`**: Librería de bajo nivel que proporciona mapeo de pines GPIO y funciones de acceso directo

  #### Variables de almacenamiento

  En esta sección se definen las rutas de los archivos de entrada y salida para el proceso de conversión:
  
  ```C
  const char *nombre_archivo_entrada = "hardware.bin";
  const char *nombre_archivo_salida  = ".tempHex.c";
  ```
  
  Estas constantes permiten identificar el bitstream generado por APIO y especificar dónde almacenar el archivo intermedio C. Este diseño facilita cambios de rutas sin modificación del código fuente principal.

  #### Conversión del bitstream binario a código C

  Etapa fundamental que transforma el archivo binario del bitstream en un vector C compilable. La función `convertir_binario_a_c()` realiza esta conversión de forma automática:

  <p align="center">
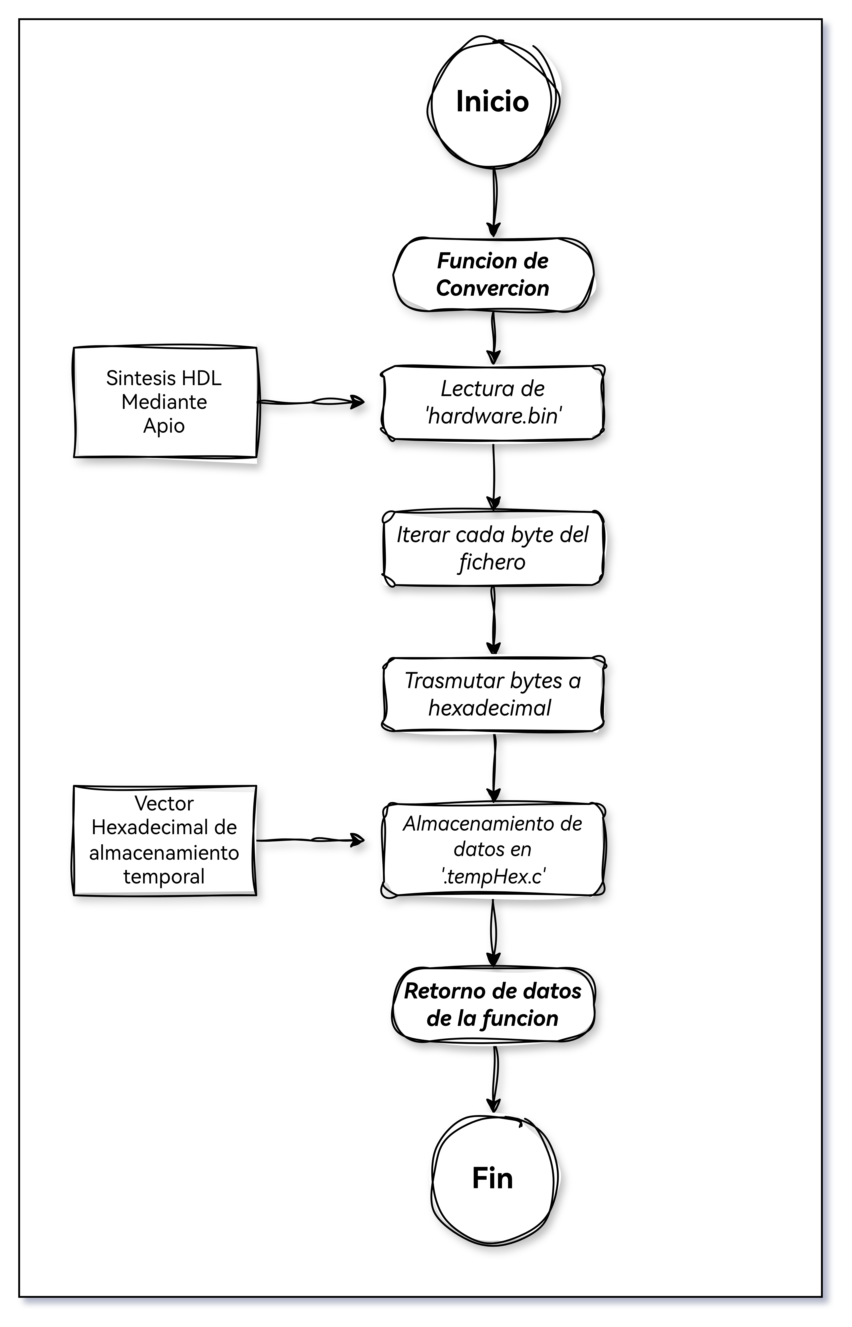
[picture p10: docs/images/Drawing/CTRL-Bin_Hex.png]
Flujo de conversión de bitstream binario a código C
  
  </p>

  ```C
  void convertir_binario_a_c(const char *nombre_archivo_entrada,
                             const char *nombre_archivo_salida);
  ```
  El algoritmo implementa los siguientes pasos:

  1. **Lectura binaria**: Abre `hardware.bin` en modo lectura binaria.
  2. **Iteración**: Recorre cada byte del fichero secuencialmente.
  3. **Conversión hexadecimal**: Transforma cada valor a notación hexadecimal (`0xXX`).
  4. **Generación de vector**: Construye el vector `bitmap[]` completo con todos los bytes.
  5. **Cierre de ficheros**: Finaliza la operación cerrando ambos ficheros.

  El resultado es un fichero C que contiene el bitstream en formato adecuado para inclusión directa en el código fuente, dentro de este archivo se genera la siguiente estructura:
  El resultado es un fichero C que contiene el bitstream como un array de bytes, listo para inclusión directa en el código fuente. Ejemplo del contenido generado:

  ```c
  char bitmap[] = { 0x00, 0xAF, 0x10, ... };
  ```

  El fichero (por ejemplo `.tempHex.c`) se incorpora con `#include ".tempHex.c"` y proporciona `bitmap` y su longitud. El firmware transmite estos bytes por SPI (bit-banging) desde la Raspberry Pi hacia la FPGA usando los pines GPIO definidos; opcionalmente puede almacenarse en la EEPROM para persistencia.

  #### Mapeo de pines GPIO

  La interfaz SPI utiliza seis líneas GPIO del conector J8 de Raspberry Pi:
  
  ```C
  #define SDO     RPI_BPLUS_GPIO_J8_35    // Serial Data Out (MOSI)
  #define SCLK    RPI_BPLUS_GPIO_J8_36    // Serial Clock
  #define CSN     RPI_BPLUS_GPIO_J8_37    // Chip Select Negado
  #define SDI     RPI_BPLUS_GPIO_J8_38    // Serial Data In (MISO)
  #define CRESETB RPI_BPLUS_GPIO_J8_40    // Config Reset (activo bajo)
  #define CDONE   RPI_BPLUS_GPIO_J8_15    // Config Done (entrada)
  ```

  | Nombre | Pin J8 | Dirección | Descripción |
  |---|---|---|---|
  | **SDO** | 35 | Salida | Transmisión de datos → FPGA |
  | **SCLK** | 36 | Salida | Reloj de serialización |
  | **CSN** | 37 | Salida | Chip-Select (0 = activo) |
  | **SDI** | 38 | Entrada | Recepción de datos ← FPGA |
  | **CRESETB** | 40 | Salida | Reset de configuración (0 = reset) |
  | **CDONE** | 15 | Entrada | Indicador de carga completada |
  
  #### Operaciones de línea

  El firmware implementa funciones de manipulación de bajo nivel para cada señal:
  
  ```C
  void assert_sdo();      // Establecer SDO = 1
  void dessert_sdo();     // Establecer SDO = 0
  void assert_sclk();     // Establecer SCLK = 1
  void dessert_sclk();    // Establecer SCLK = 0
  void assert_ss();       // Establecer CSN = 0 (chip seleccionado)
  void dessert_ss();      // Establecer CSN = 1 (chip deseleccionado)
  void sendbyte(char data);  // Transmitir byte completo
  ```

  Estas funciones abstraen el control de GPIO, permitiendo la serialización sincronizada del bitstream.

  #### Compilación y ejecución

  El código fuente se compila enlazando contra la librería **bcm2835**:

  ```bash
  gcc -Wall -O2 iDuck-RP-Upload.c -o iDuck-RP-Upload -lbcm2835
  ```

  Flags utilizados:
  - `-Wall`: Habilita todos los warnings del compilador
  - `-O2`: Optimización de nivel 2 (rendimiento)
  - `-lbcm2835`: Enlace con la librería bcm2835

  La ejecución requiere privilegios de root para acceso directo a memoria GPIO:

  ```bash
  sudo ./iDuck-RP-Upload
  ```

  > **Importante**: El acceso a GPIO requiere ejecución con `sudo`. Se recomienda configurar el usuario dentro del grupo `gpio` para evitar esta requering en futuras ejecuciones.

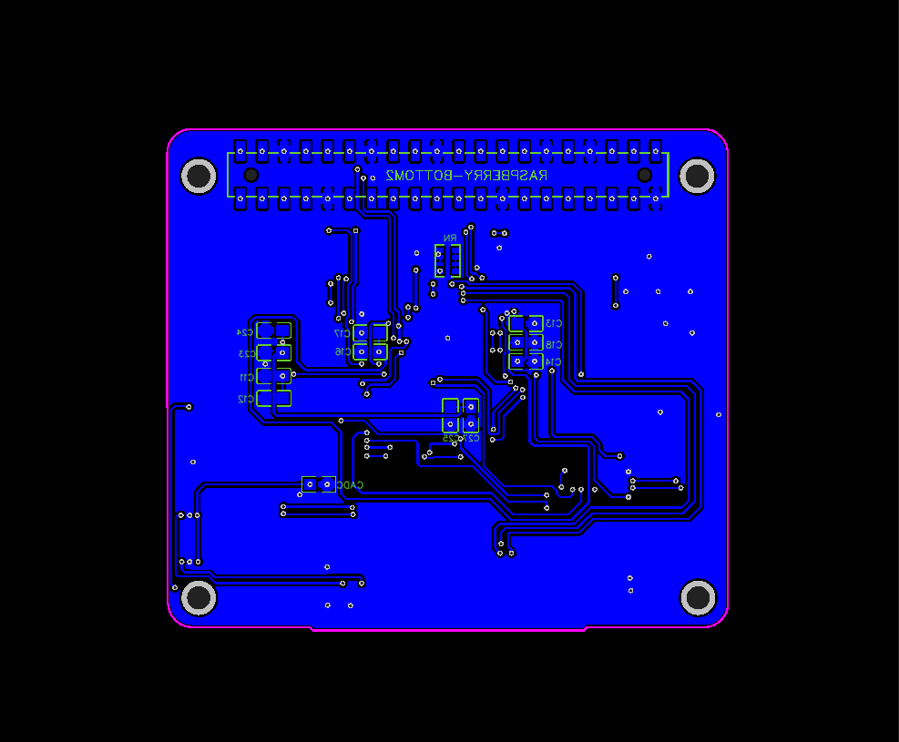
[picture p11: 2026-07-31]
hardware/boards-iCesDuck/v1-a1/exports/images/PCB_PCB_iCESDuck-BOT.png

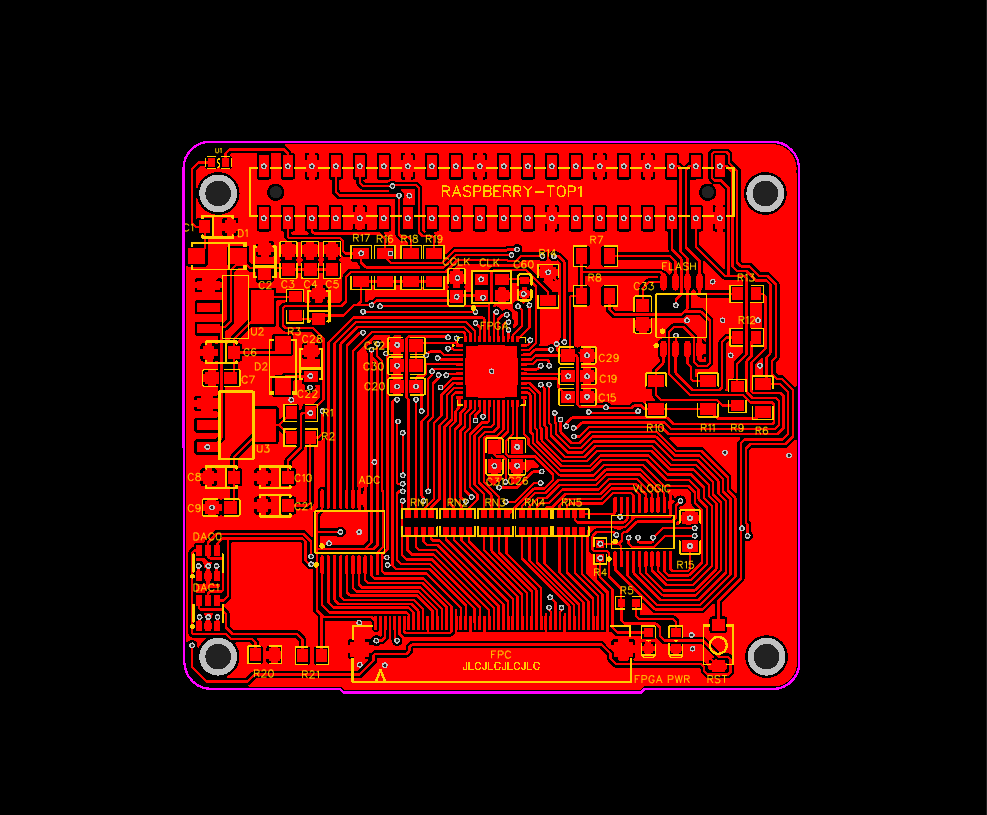
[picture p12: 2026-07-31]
hardware/boards-iCesDuck/v1-a1/exports/images/PCB_PCB_iCESDuck-TOP.png

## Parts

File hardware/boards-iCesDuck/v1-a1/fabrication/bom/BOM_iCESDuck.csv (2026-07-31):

ID | Name | Designator | Footprint | Quantity | Manufacturer Part | Manufacturer | Supplier | Supplier Part | Price | Pins | 3DModel | Contributor | JLCPCB Part Class | link
1 | 47uF | CADC,C11,C12,C23,C24,C25,C27,C17,C18,C13,C14,C16,C3,C4,C5,C7,C9,C15,C19,C20,C30,C31,C33,C26,C29,C32,CCLK | C0805 | 27 | C2012X5R1A476MTJ00E | TDK | LCSC | C76636 | 0.391 | 2 | C0805_L2.0-W1.3-H1.3 | lcsc | Extended Part | https://lcsc.com/eda_search?q=C76636&%26type=1&ref=editor
2 | 130Ω | RN,RN4,RN5,RN1,RN2,RN3 | RES-ARRAY-SMD_0603-8P-L3.2-W1.6-BL | 6 | 4D03WGJ0131T5E | UNI-ROYAL(厚声) | LCSC | C425191 | 0.005 | 8 | R0603-8P_L3.2-W1.6-H0.6 | LCSC | Extended Part | https://lcsc.com/eda_search?q=C425191&%26type=1&ref=editor
3 | FH-00148 | RASPBERRY-BOTTOM2,RASPBERRY-TOP1 | HDR-SMD_40P-P2.54-V-F-R2-C20-S7.1-EH | 2 | FH-00148 | Liansheng(连盛) | LCSC | C2685092 | 0.545 | 40 | HDR-SMD_40P-P2.54-F-LS-2X20P-R2 | LCSC | Extended Part | https://lcsc.com/eda_search?q=C2685092&%26type=1&ref=editor
4 | 47uF | C21,C1,C2,C6,C8,C10,C22,C28 | CAP-SMD_L3.2-W1.6 | 8 | CA45-A-10V-47uF-M | CEC(振华新云) | LCSC | C688949 | 0.166 | 2 | CAP-SMD_L3.2-W1.6 | LCSC | Extended Part | https://lcsc.com/eda_search?q=C688949&%26type=1&ref=editor
5 | ADS7844N | ADC | SSOP-20_L7.2-W5.3-P0.65-LS7.8-BL | 1 | ADS7844N | TI(德州仪器) | LCSC | C52610 | 8.604 | 20 | SSOP-20_L7.2-W5.3-H2.0-LS7.8-LS0.65 | LCSC | Extended Part | https://lcsc.com/eda_search?q=C52610&%26type=1&ref=editor
6 | 15pF | C60 | C0603 | 1 | CL10C150JB8NNNC | SAMSUNG(三星) | LCSC | C1644 | 0.014 | 2 | C0603_L1.6-W0.8-H0.8 | lcsc | Basic Part | https://lcsc.com/eda_search?q=C1644&%26type=1&ref=editor
7 | 1N5819_C437199 | D1,D2 | SMA_L4.4-W2.6-LS5.0-RD | 2 | 1N5819 | KEXIN(科信) | LCSC | C437199 | 0.024 | 2 | SMA_L4.4-W2.6-LS5.0-RD | LCSC | Extended Part | https://lcsc.com/eda_search?q=C437199&%26type=1&ref=editor
8 | MCP4725A1T-E/CH | DAC0,DAC1 | SOT-23-6_L2.9-W1.6-P0.95-LS2.8-BR | 2 | MCP4725A1T-E/CH | MICROCHIP(美国微芯) | LCSC | C61423 | 1.788 | 6 | SOT-23-6_L2.9-W1.6-H1.5-LS2.8-P0.95 | lcsc | Extended Part | https://lcsc.com/eda_search?q=C61423&%26type=1&ref=editor
9 | AFC01-S50FCA-00 | FPC | FPC-SMD_AFC01-S50FCC-00 | 1 | AFC01-S50FCA-00 | JS(钜硕电子) | LCSC | C262676 | 0.273 | 52 | FPC-SMD_P0.50-WS-50P | LCSC | Extended Part | https://lcsc.com/eda_search?q=C262676&%26type=1&ref=editor
10 | LED-0603_G | FPGA,PWR | LED0603_GREEN | 2 | 19-217/GHC-YR1S2/3T | EVERLIGHT(台湾亿光) | LCSC | C72043 | 0.024 | 2 | LED0603-RD_GREEN | LCEDA_Lib
11 | 100Ω | R1 | R0805 | 1 | AS05W2J0102T5E | UNI-ROYAL(厚声) | LCSC | C560481 | 0.029 | 2 | R0805_L2.0-W1.3-H0.6 | LCSC | Extended Part | https://lcsc.com/eda_search?q=C560481&%26type=1&ref=editor
12 | 0Ω | R2,R3,R9,R12,R13,R20,R21 | R0805 | 7 | AS05W2J0102T5E | UNI-ROYAL(厚声) | LCSC | C560481 | 0.029 | 2 | R0805_L2.0-W1.3-H0.6 | LCSC | Extended Part | https://lcsc.com/eda_search?q=C560481&%26type=1&ref=editor
13 | 1kΩ | R4 | R0603 | 1 | 0603WAF1001T5E | UNI-ROYAL(厚声) | LCSC | C21190 | 0.013 | 2 | R0603 | lcsc | Basic Part | https://lcsc.com/eda_search?q=C21190&%26type=1&ref=editor
14 | 2.2kΩ | R5 | R0603 | 1 | 0603WAF2201T5E | UNI-ROYAL(厚声) | LCSC | C4190 | 0.002 | 2 | R0603 | lcsc | Basic Part | https://lcsc.com/eda_search?q=C4190&%26type=1&ref=editor
15 | 10kΩ | R6,R7,R8,R10,R11,R14,R15,R16,R17,R18,R19 | R1206 | 11 | FRP1206J103 TS | FOJAN(富捷) | LCSC | C3013377 | 0.006 | 2 | R1206_L3.2-W1.6-H0.6 | lcsc |  | https://lcsc.com/eda_search?q=C3013377&%26type=1&ref=editor
16 | TS-1088R-02026 | RST | SW-SMD_L3.9-W3.0-P4.45 | 1 | TS-1088R-02026 | XUNPU(讯普) | LCSC | C455280 | 0.063 | 2 | SW-SMD_L3.9-W2.9-H2.0-LS4.8 | LCSC | Extended Part | https://lcsc.com/eda_search?q=C455280&%26type=1&ref=editor
17 | AMS1117-3.3 | U2 | SOT-223-4_L6.5-W3.5-P2.30-LS7.0-BR | 1 | AMS1117-3.3 | UMW(广东友台半导体) | LCSC | C347222 | 0.049 | 4 | SOT-223-4P_L6.5-W3.5-H1.6-LS7.0-P2.30 | LCSC | Extended Part | https://lcsc.com/eda_search?q=C347222&%26type=1&ref=editor
18 | AMS1117-1.2 | U3 | SOT-223_L6.7-W3.5-P2.30-BR | 1 | AMS1117-1.2 | UMW(广东友台半导体) | LCSC | C347218 | 0.05 | 4 | SOT-223-4P_L6.5-W3.5-H1.6-LS7.0-P2.30 | LCSC | Extended Part | https://lcsc.com/eda_search?q=C347218&%26type=1&ref=editor
19 | TXB0108PWR | VLOGIC | TSSOP-20_L6.5-W4.4-P0.65-LS6.4-BL | 1 | TXB0108PWR | TI(德州仪器) | LCSC | C53406 | 0.608 | 20 | TSSOP-20_L6.5-W4.4-H1.0-LS6.4-P0.65 | lcsc | Extended Part | https://lcsc.com/eda_search?q=C53406&%26type=1&ref=editor
20 | 48MHz | CLK | OSC-SMD_4P-L3.2-W2.5-BL_SIT8008BI | 1 | S3D48.000000B20F30T | SCTF(星通时频) | LCSC | C387440 |  | 4 | OSC-SMD_4P-L3.2-W2.5-H1.0 | LCSC | Extended Part | https://lcsc.com/eda_search?q=C387440&%26type=1&ref=editor
21 | W25Q64JVSSIM | FLASH | SOIC-8_L5.2-W5.2-P1.27-LS8.0-BL | 1 | W25Q64JVSSIM | WINBOND(华邦) | LCSC | C5362615 | 4.714 | 8 | SOIC-8_L5.2-W5.2-P1.27-LS8.0-BL | lcsc | Extended Part | https://lcsc.com/eda_search?q=C5362615&%26type=1&ref=editor
22 | 0494001.NR | U1 | F0603 | 1 | 0494001.NR | Littelfuse(美国力特) | LCSC | C142652 | 0.072 | 2 | F0603_L1.7-W0.9-H0.7 | LCSC | Extended Part | https://lcsc.com/eda_search?q=C142652&%26type=1&ref=editor
23 | ICE40UP5K-SG48I | FPGA | QFN-48_L7.0-W7.0-P0.50-TL-EP5.4-1 | 1 | ICE40UP5K-SG48I | LATTICE(莱迪思) | LCSC | C2678152 | 8.564 | 49 | QFN-48_L7.0-W7.0-P0.50-TL-EP5.4-1 | LCSC | Extended Part | https://lcsc.com/eda_search?q=C2678152&%26type=1&ref=editor

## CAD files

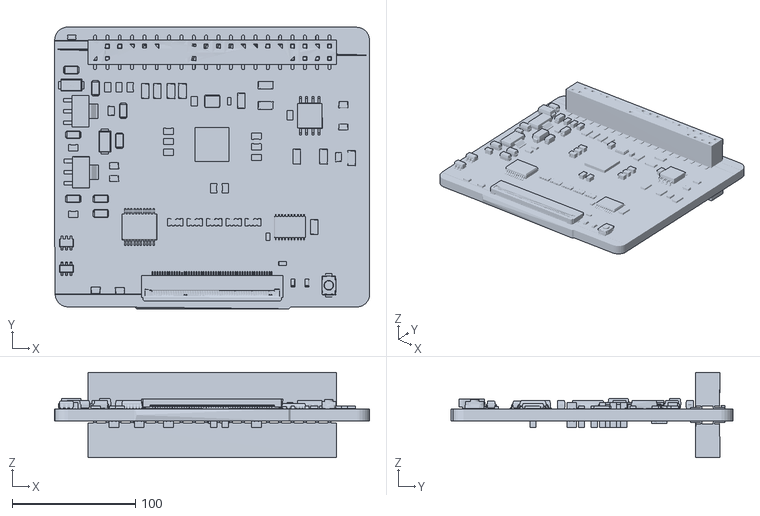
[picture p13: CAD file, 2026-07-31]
hardware/boards-iCesDuck/v1-a1/exports/3d/OBJ_PCB_iCESDuck-ShieldControler.obj
255.3 x 228.3 x 69.1

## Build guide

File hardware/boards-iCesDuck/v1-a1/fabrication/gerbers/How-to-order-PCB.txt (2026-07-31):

How to Order PCB

Please refer to:
https://docs.easyeda.com/en/PCB/Order-PCB
